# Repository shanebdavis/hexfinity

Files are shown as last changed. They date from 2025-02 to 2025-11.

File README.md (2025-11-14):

Hexfinity Logo
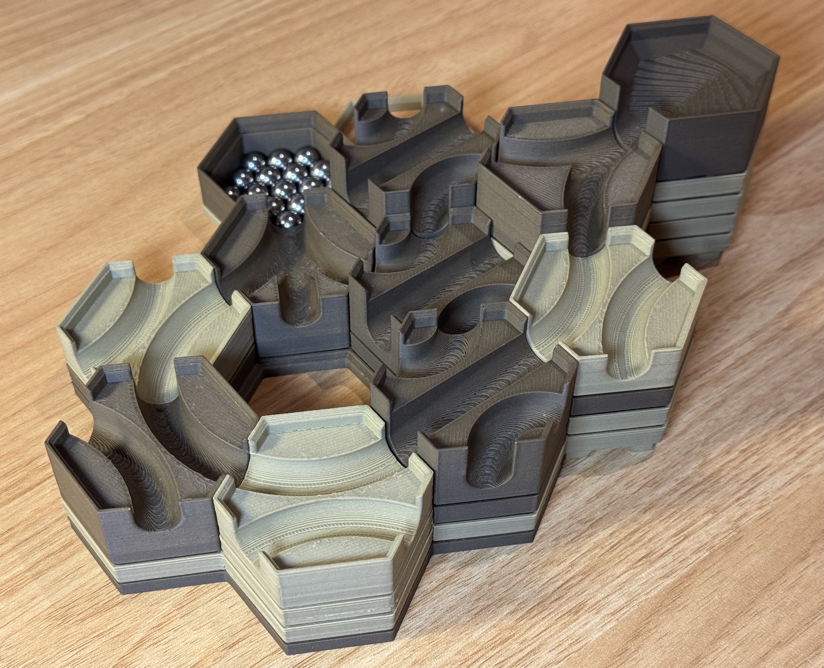
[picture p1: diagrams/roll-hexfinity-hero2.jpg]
Hexfinity Hero


> Note: I've been release new stuff all year, but I haven't had time to update this Repo. Visit me on [MakerWorld.com/en/@Kanjirevilo](https://makerworld.com/en/@Kanjirevilo) to see the latest. If you want to see me updating this repo, leave a comment there - I'm more likely to see it. If there is interest in this repo, I'll definitly do more to keep it up to date. Cheers!

# Hexfinity: Modular Hexagonal Grid System

- [Hexfinity Specification](HEXFINITY.md) Just want the specs? Go here!
- [Roll Hexfinity](ROLL_HEXFINITY.md) The ball rolling system specs
- [Stor Hexfinity](STOR_HEXFINITY.md) The hexagonal storage system specs

## Introduction

Hexagons are the bestagons! If you're here, it's because you love modular systems, you appreciate efficient tiling, and you want to build something with infinite creative possibilities. Welcome to **Hexfinity**, an open-source modular system that combines the best aspects of **ball rolling sculptures** and **hexagonal storage solutions**.

### Tribute to Gridfinity

I'm a huge fan of Zach Freedman's Gridfinity [Gridfinity on Thangs](https://thangs.com/designer/ZackFreedman/3d-model/Gridfinity%20Baseplates-60925) and [Gridfinity on YouTube](https://www.youtube.com/watch?v=ra_9zU-mnl8). I was inspired by his work to create Hexfinity. Now only is Hexfinity inspired by Gridfinity, but it is also designed to be compatible with it - at least as compatible as possible given how square grids and hexagonal grids are different.

### Why Hexagons?

- **Maximum Connectivity**: Hexagons connect to **six** neighbors, whereas squares connect to four and triangles to three. This maximizes the number of inputs and outputs, allowing for more flexible and intricate structures.
- **Efficient Space Usage**: Hexagons offer the **best ratio of area to perimeter** for tiling the plane, making them optimal for compact and efficient storage.
- **Aesthetic Appeal**: Hexagons just look better. They form natural patterns that are visually satisfying and structurally strong.
- **Better Ball Rolling**: More connections mean more pathways for balls to roll, enabling **dynamic, customizable marble runs** that are both fun and engaging.

## The Two Components of Hexfinity

Hexfinity is divided into **two major components**, each serving a unique purpose but built on the same core principles:

### 1. [RollHexfinity](ROLL_HEXFINITY.md) (The Ball Rolling System)

RollHexfinity is designed for creating highly customizable **ball rolling sculptures**. Unlike traditional marble mazes that offer limited configurations, RollHexfinity provides:

- **Modular Hexagonal Bricks**: A small set of core bricks enables infinite configurations.
- **Stackability**: Pieces can be layered while still allowing balls to roll through tunnels.
- **Standardized Ball Size**: Uses **8mm steel bearings**, a popular choice included with **Bambu Lab's Maker Kit**.
- **Controlled Slopes**: Ball paths follow structured height increments of **7mm**, ensuring smooth rolling motion.
- **Compatibility with Gridfinity**: Includes **adapter plates** that allow you to integrate RollHexfinity with the popular Gridfinity system.

### 2. [StorHexfinity](STOR_HEXFINITY.md) (The Hexagonal Storage System)

Hexfinity isn't just for rolling balls—it's also a **storage system** optimized for hexagonal layouts. StorHexfinity provides:

- **Hexagonal Containers**: Available in various sizes, maintaining modularity while maximizing storage efficiency.
- **Flexible Grid Compatibility**: Designed to integrate with square-based storage solutions.
- **Efficient Circular Storage**: Ideal for storing spherical objects (e.g., bearings, marbles, beads) more effectively than square containers.
- **Customizable Dividers**: Allows for custom compartment layouts using **60-degree and 120-degree angles**.

## Roll Hexfinity Technical Specifications

- **Roll channel diameter**: 10mm
- **Recommended ball size**: 8mm steel bearings
- **Entry and exit points**: Balls enter and exit bricks at the center of a side, with the center of the 10mm channel positioned at a multiple of 7mm from the base (e.g., 14mm, 21mm, etc.). For example, the 14mm opening starts at 9mm and extends to 19mm from the base.
- **Path grades**: Ball paths are either flat or descend by increments of 7mm, 14mm, or more. For the standard 21mm bricks, the minimum slope is **7mm over 42mm (17% grade)**.

## Building with Hexfinity

### How to Print

- BambuLab A1Mini/A1/X1/P1 Print-ready profiles are available on [MakerWorld.com/en/@Kanjirevilo](https://makerworld.com/en/@Kanjirevilo)
- Or pick the models ala carte from this repo: [models](./models)

More details on printing:

- **Material Estimate**: A full brick (~21mm tall) weighs ~9g.
- **Recommended Filament**: PLA works great. Wood PLA is a little snug at first, but it gets looser with use. PETG works fabulously.
- **Printer Compatibility**: Designed for FDM printers with a 0.4mm nozzle

### Assembly

- **Stackable Design**: Pieces interlock securely for stable constructions.
- **Tunnel-Friendly**: Tunnels are automatically created when stacking bricks with rolling paths.
- **Flexible Configurations**: Can be combined into long paths, drops, turns, and multi-level structures.

## Future Plans

- **More Adapter Plates**: Expand compatibility between Hexfinity and Gridfinity.
- **Additional Hexagonal Storage Modules**: Customizable dividers for better organization.
- **Hex-to-Grid Interchangeability**: Potential for Gridfinity pieces to sit atop Hexfinity bases.

## Contributing

This project is open-source! If you want to contribute:
1 Fork the repository.
2 Print and test the existing models.
3 Suggest improvements, new designs, or additional modular elements.
4 Submit a pull request!

## License

Hexfinity is licensed under the **Creative Commons Attribution 4.0 International (CC BY 4.0) License**. This means you are free to use, modify, remix, and share the designs **as long as you provide proper attribution** back to:

1. I prefer you link back to my [MakerWorld.com/en/@Kanjirevilo](https://makerworld.com/en/@Kanjirevilo) profile
2. But, you can also link to this github repo: [Hexfinity](https://github.com/shanebdavis/hexfinity)

And I want to hear about your creations! Add comments on one of my MakeWorld Hexfinity models or here under [issues](./issues)

# Get Started

Print, build, experiment, and enjoy! **Hexagons are the bestagons, and now you can prove it with your own hands.**

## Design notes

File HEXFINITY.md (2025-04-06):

Hexfinity Logo

# Hexfinity Specification

## The Hexfinity Grid - with Max Gridfinity Compatibility

Inspired by the Gridfinity, I started with the core gridfinity design principles:

- **42mm**: Flat-to-flat width of the hex grid(Y-repetition distance `yRep = 42mm`)
- **7mm**: Height increments

But since I'm using regular hexagons, the above dimensions imply some decidedly non-gridfinity dimensions. But what are you going to do? Hexes are just better than squares!

- **48.4974mm:** hex grid diameter (X-repetition distance `xRep = yRep / cos(π \* 30 / 180)`)
- **24.2487mm:** hex grid radius IS the tiling hex edge length (because, hexagons are the bestagons!) (`xRep / 2`)
- **12.1244mm:** 1/2 edge (`hRep / 2`)
- **36.3731mm:** 3/2 edge lengths (`3 * hRep / 2`)
- **72.7461mm:** 3 edge lengths (`3 * hRep`)

## Hexfinity Tiles (and Bricks)

While hexfinity grid defines our infinite tiling of the plane, in the real world our tiles need some clearance to fit together. To keep things easy, I also started with some nice round values:

- **48mm:** hex tile diameter
- **24mm:** hex tile radius

But that in turn implies these hex-tacular numbers:

- **41.5692:** flat-to-flat width of a hex tile

## Inter-tile Clearance

Which means the clearance between two flat tile edges is:

- **0.4308mm:** tile flat-edge-to-flat-edge clearance `42mm - 41.5692mm`
- **0.2154mm:** half the clearance `0.4308mm / 2`

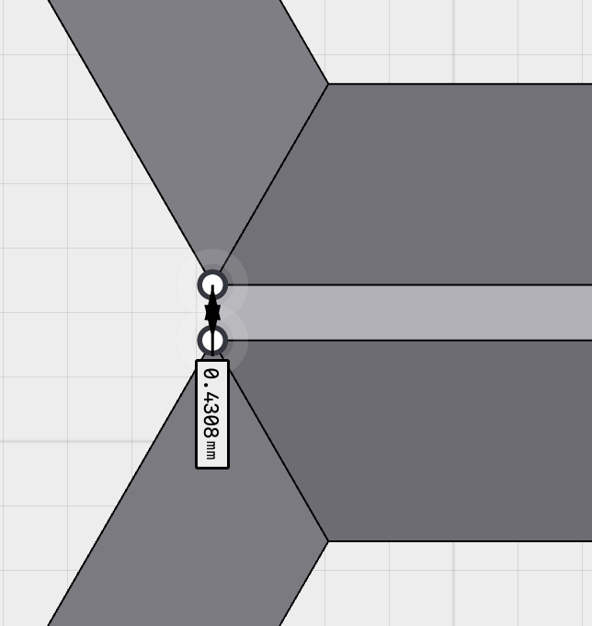
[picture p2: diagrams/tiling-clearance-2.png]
Inter-tile Clearance
- 

## Interlock

The interlock is the key to making the tiles fit together. Inspired by the Gridfinity interlock, I designed a simple interlock that fits together with a bit of clearance. The "outer" interlock rises up from the top of a tile 5mm and wraps around the "inner" interlock of the tile above. Another way to think about it is the "inner" interlock is cut out of the bottom of tile tile while the "outer" interlock is added to the top of the tile. Or, the "outer" interlock is the tongue and the "inner" interlock is the grove.

### Outer Interlock

- **Outer Interlock "tongue"** (extends on top of a tile)

  - **Profile at Hexagon _Corners_**
    - **1.8mm** thick at corners of the hexagon (**X-dimension**)
    - **5mm** outer height (**Z-dimension**)
    - **3.2mm** inner height (**Z-dimension**)
  - **1.5588mm** effective thickness of the interlock along edges of the edges of the hexagon (sin(π/3) \* 1.8)

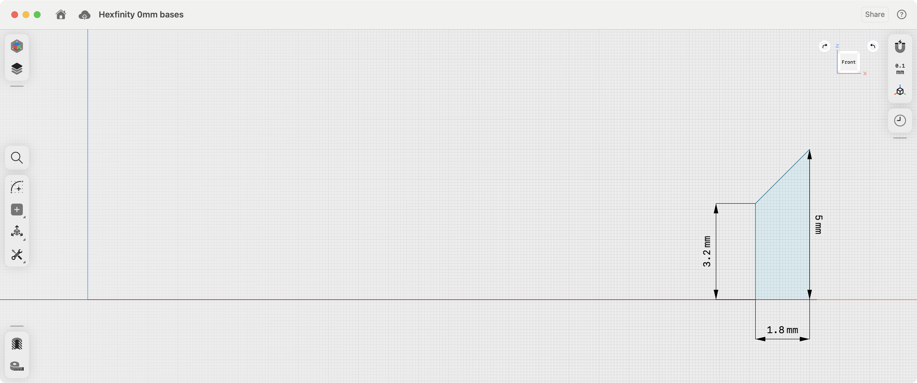
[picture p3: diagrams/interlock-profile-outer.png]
Interlock Profile Outer
- Outer interlock profile: 
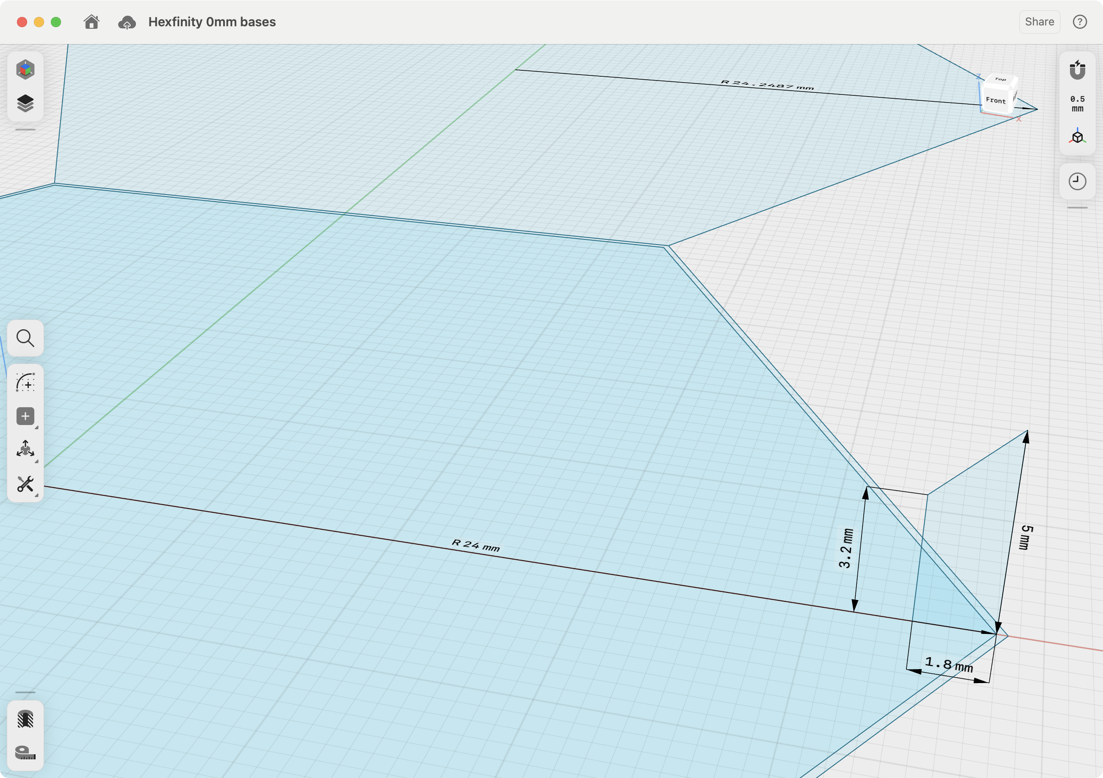
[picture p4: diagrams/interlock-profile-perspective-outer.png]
Interlock Profile Outer Perspective
- Outer interlock profile perspective: 
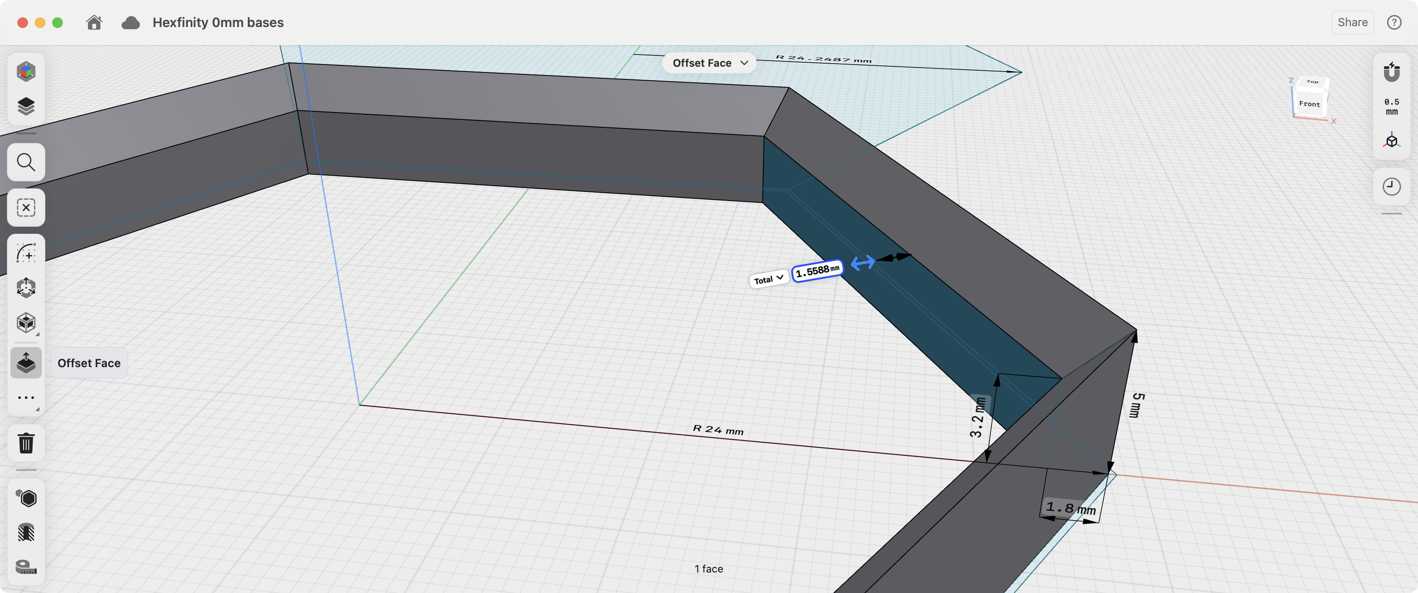
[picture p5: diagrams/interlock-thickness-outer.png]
Outer Interlock Thickness
- Outer interlock thickness: 

### Inner Interlock

- **Inner Interlock "grove"** (cut out of the bottom of a tile)

  - **Profile at Hexagon Corner**
    - **2.1mm** thick at corners of the hexagon
    - **3mm** inner height (**Z-dimension**)
    - **5.1mm** outer height (**Z-dimension**)
  - **1.8187mm** thick along edges of the hexagon (sin(π/3) \* 2.1)

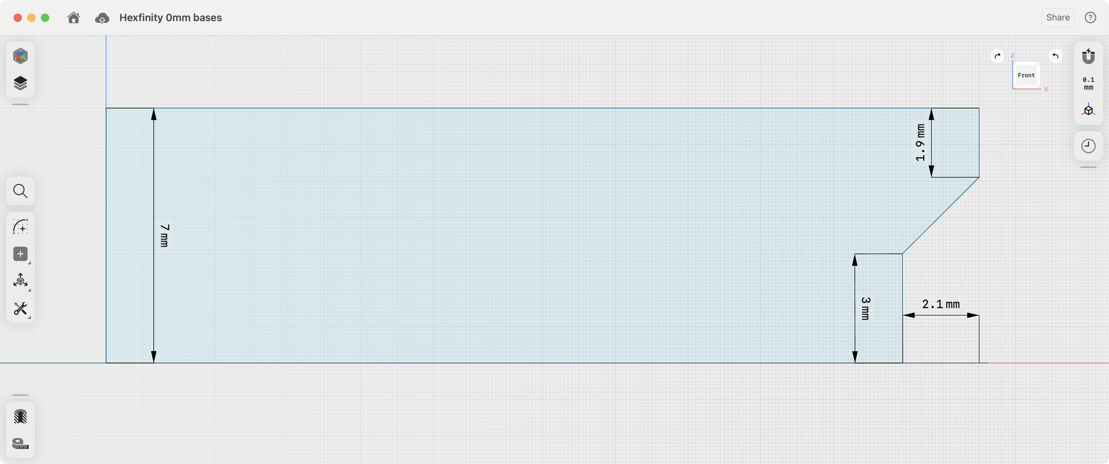
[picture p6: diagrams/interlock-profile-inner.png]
Interlock Profile Inner
- Inner interlock profile: 
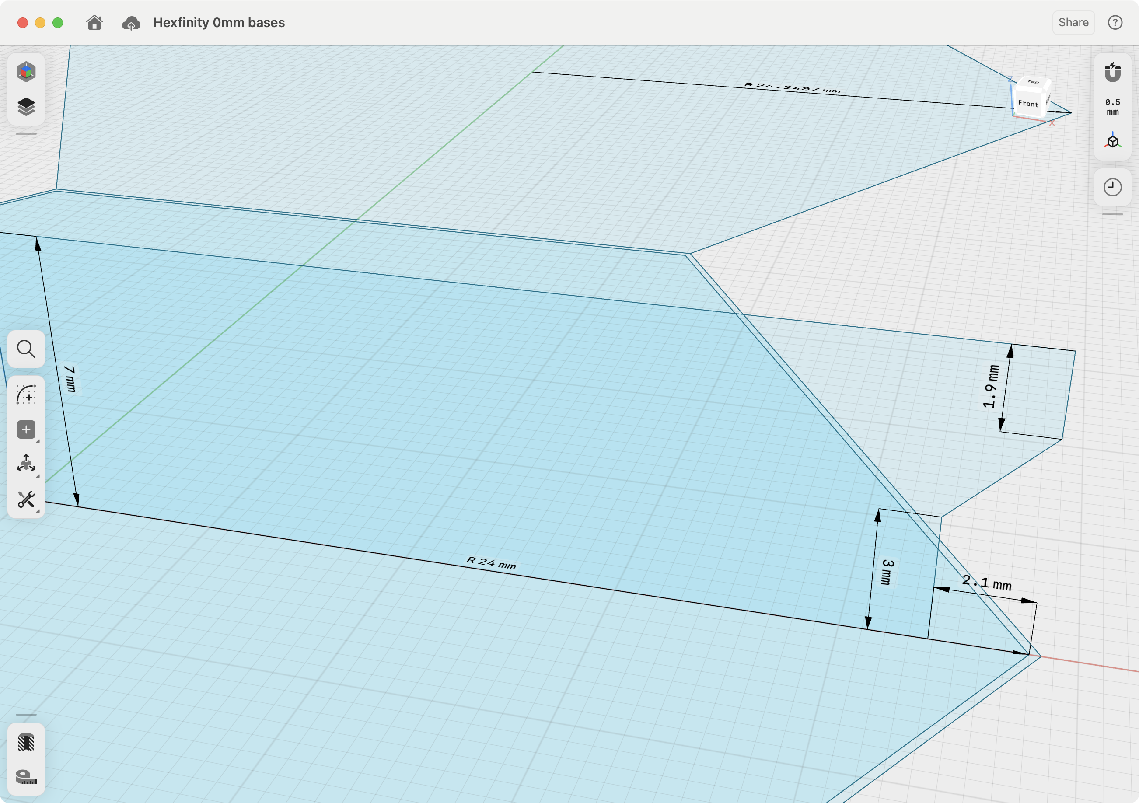
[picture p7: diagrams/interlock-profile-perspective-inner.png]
Interlock Profile Inner Perspective
- Inner interlock profile perspective: 
- Inner interlock thickness: Inner Interlock Thickness

### Both Inner and Outer Interlock

Here you can see how they fit together.

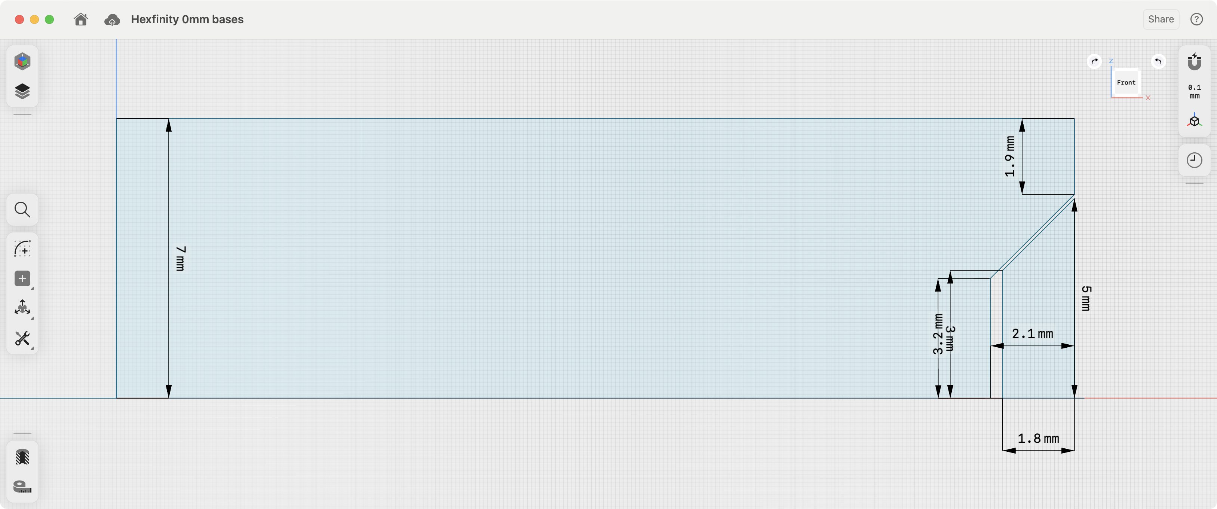
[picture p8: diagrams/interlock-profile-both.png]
Interlock Profile Both
- Interlock profile both: 
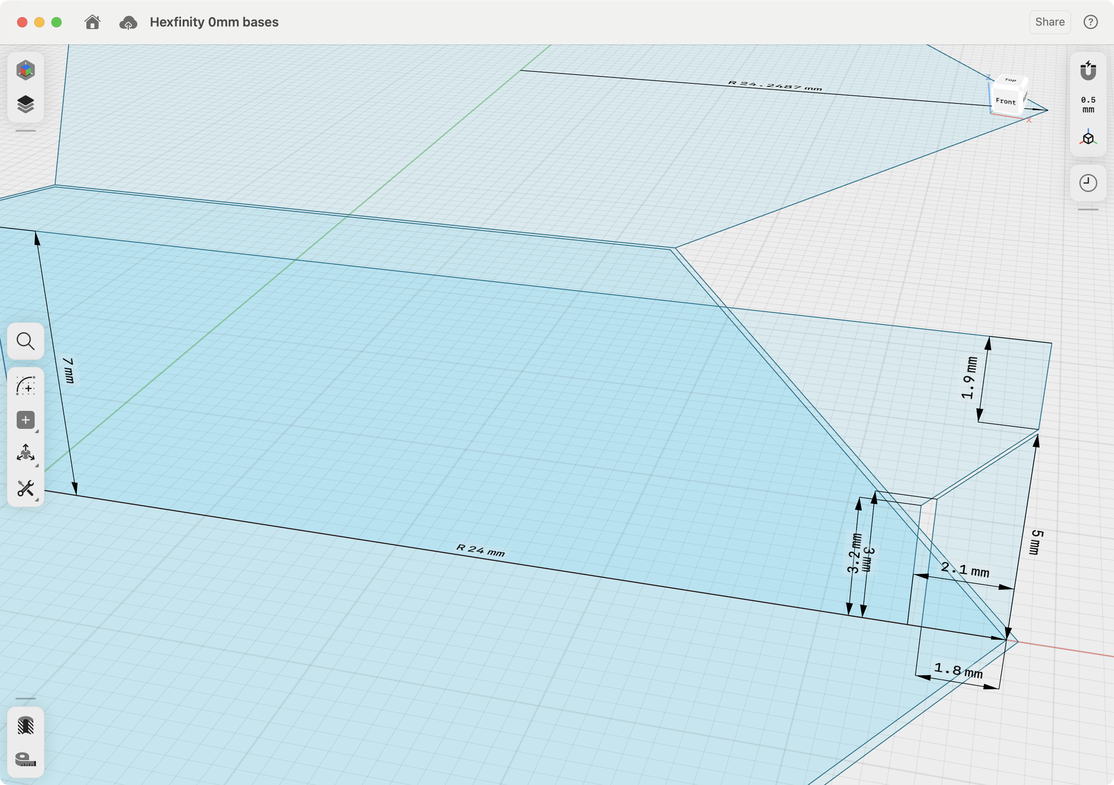
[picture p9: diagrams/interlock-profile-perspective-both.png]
Interlock Profile Both Perspective
- Interlock profile both perspective:

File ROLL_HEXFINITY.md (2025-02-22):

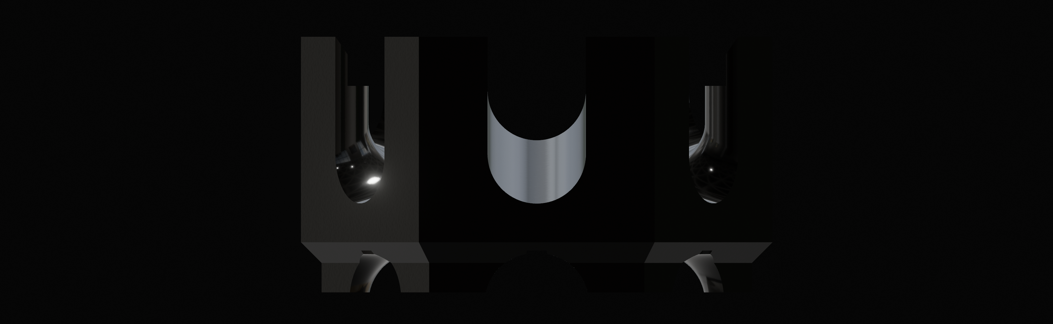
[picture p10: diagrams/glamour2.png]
Roll Hexfinity


# Roll Hexfinity - Infinite Ball Rolling System

- See the [Hexfinity Specification](./HEXFINITY.md) for the core principles of the Hexfinity ecosystem.

## Tiles, Plates and Bricks: 3x Plates == 1x Bricks (same as LEGO)

Roll Hexfinity uses the Hexfinity system, and it leverages the interlock and stainability. For easy reference, we'll use the analogy of LEGO to describe the system:

- **tile:** any placable piece in the hexfinity system
- **plate:** a 7mm hexfinity tile
- **brick:** a 21mm hexfinity tile (3x plates)

## Roll Hexfinity Tiles

Just want to print and play? Find all the models you need:

- Roll Hexfinity: [models/roll-hexfinity](./models/roll-hexfinity)
- Hexfinity Bases: [models/hexfinity-bases](./models/hexfinity-bases)
- Hexfinity Plates: [models/hexfinity-plates](./models/hexfinity-plates)

Want to customize and make your own?

- Hexfinity Reference Tiles: [models/hexfinity-reference-tiles](./models/hexfinity-reference-tiles)
- Roll Hexfinity cut-outs: [models/roll-hexfinity-cut-outs](./models/roll-hexfinity-cut-outs)

## The Roll Hexfinity Hex-to-Hex Interface System

Given the basics of Hexfinity, the key to Roll Hexfinity is how balls roll from one brick to the next:

1. **8mm:** ball diameter
2. **10mm:** ball path diameter

The center of ball paths enter and exit tiles in the center of an edge and at heights which are a multiple of 7mm from the base of the tile. The standard 3-path brick has 3 entrances at 21mm and 3 exists at 14mm:

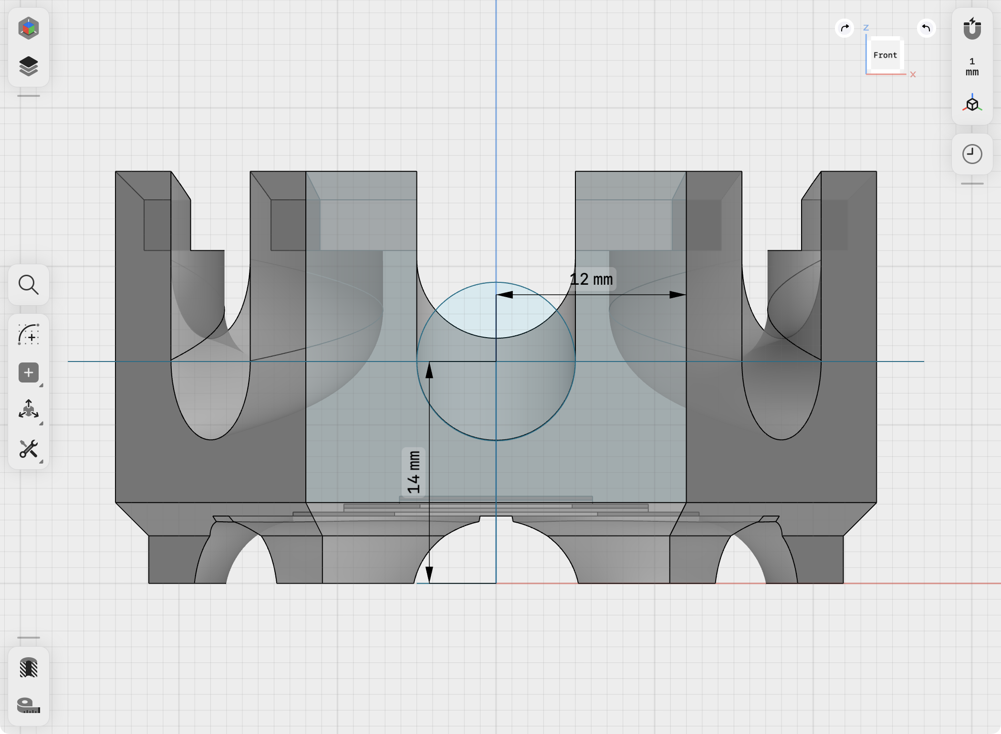
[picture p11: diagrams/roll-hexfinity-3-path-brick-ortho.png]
Ball Path Heights
- Example exit from the 3-path brick (ortho view): 
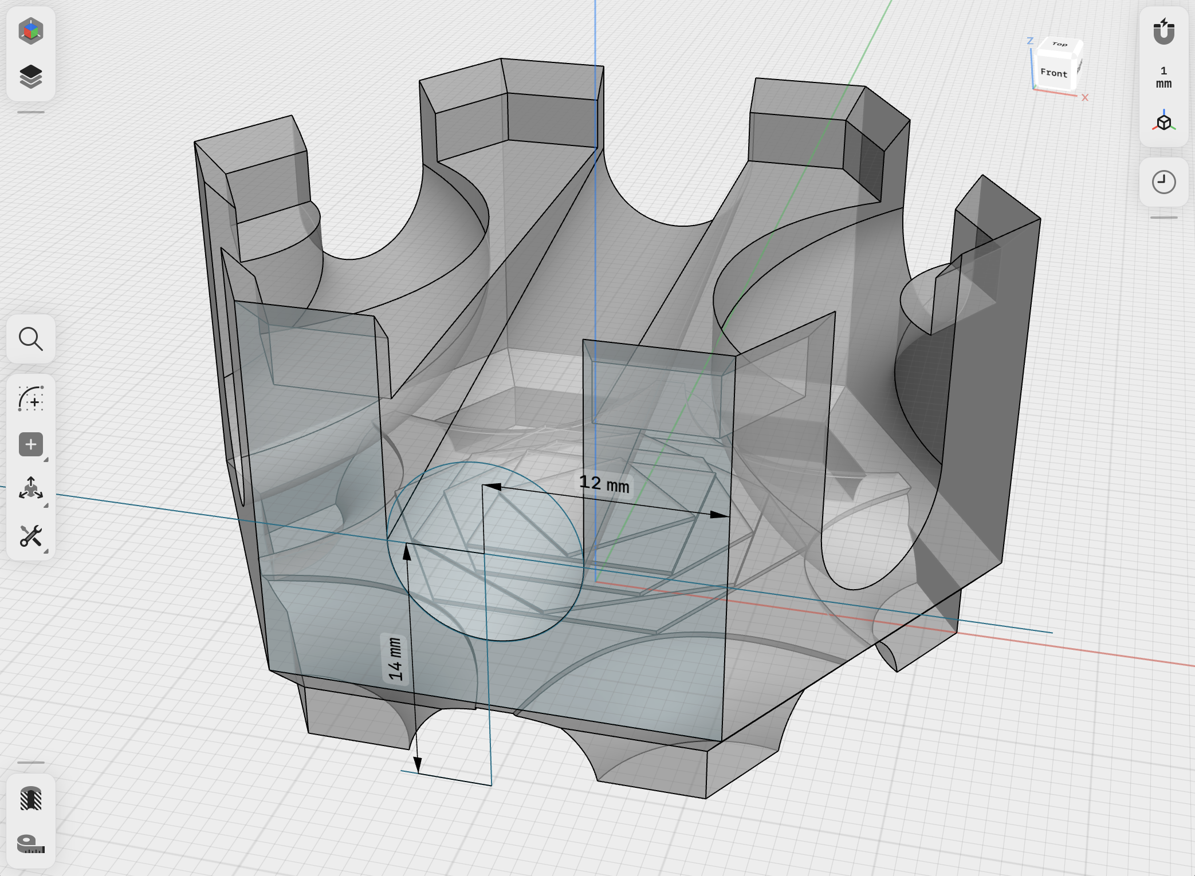
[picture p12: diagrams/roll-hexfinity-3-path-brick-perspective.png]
Ball Path Heights
- Example exit from the 3-path brick (perspective view): 

## Roll Hexfinity Clearance Trick

To make it easy for balls to roll from one brick to the next, we slightly alter the hex-to-hex interface: we lower entrances by 0.5mm. That way if two adjacent bricks are slightly misaligned, the ball will roll smoothly down to the next brick.

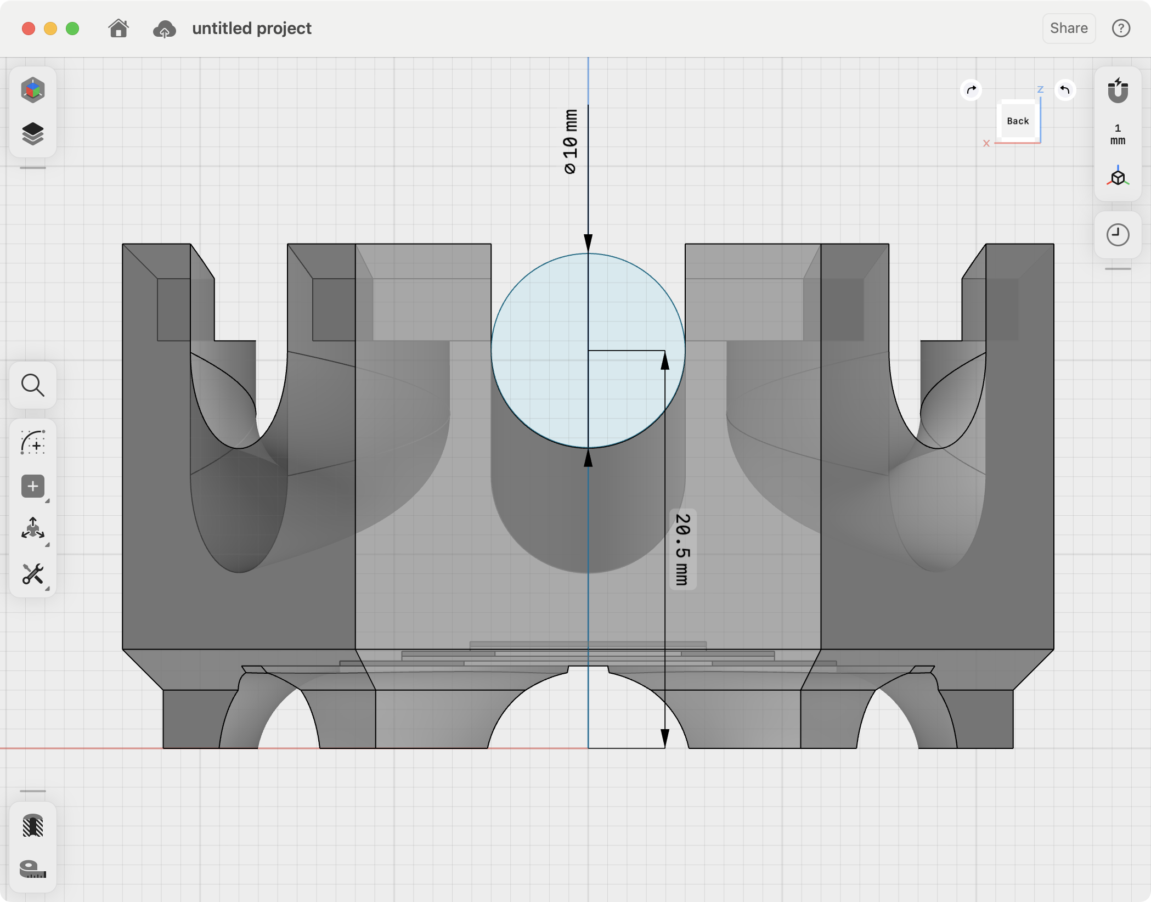
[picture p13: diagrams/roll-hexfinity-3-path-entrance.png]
Roll Hexfinity Clearance Trick
- Example entrance: 

## The Roll Hexfinity Tunnel-Compatible Base

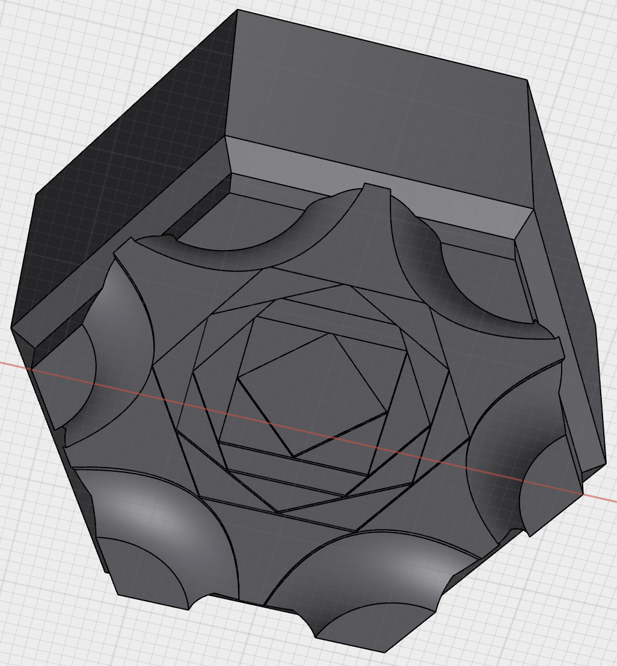
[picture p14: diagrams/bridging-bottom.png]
Bottom of a 3-path brick

What's up with the bottom of the brick?

The last, and trickiest part of the Roll Hexfinity system is the tunnel-compatible base. We need to achieve the following:

1. Roll-hexfinity tiles can be stacked without preventing balls from rolling through the tile underneath.
2. This thing needs to be 3D printable!
3. Oh, and we want it to look good :).

The first is pretty easy - we just need a clear path between every two edges of the underside of the tile. But this creates a large void in the center of the tile which 3D printers have a hard time bridging. Therefor I engineered a seemingly complex, but effective cut-out that gives the slicer the right hints to build up a bridge in layers. Last, I noticed when stacking tiles that this cut-out was visible when it didn't need to be. So, I moved the cut-out down 1mm to hide it without sacrificing the goals #1 and #2.

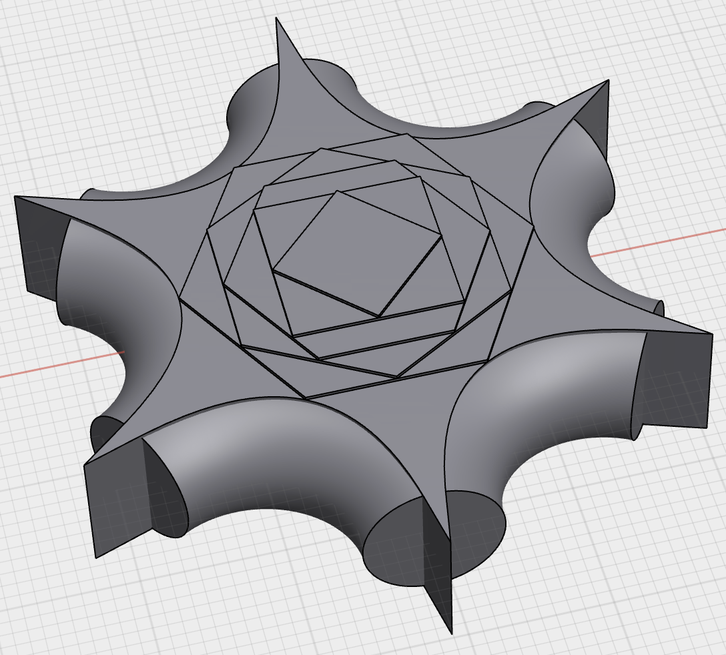
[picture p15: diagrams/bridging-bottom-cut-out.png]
Bridging Cut-Out
- Bridging cut-out:

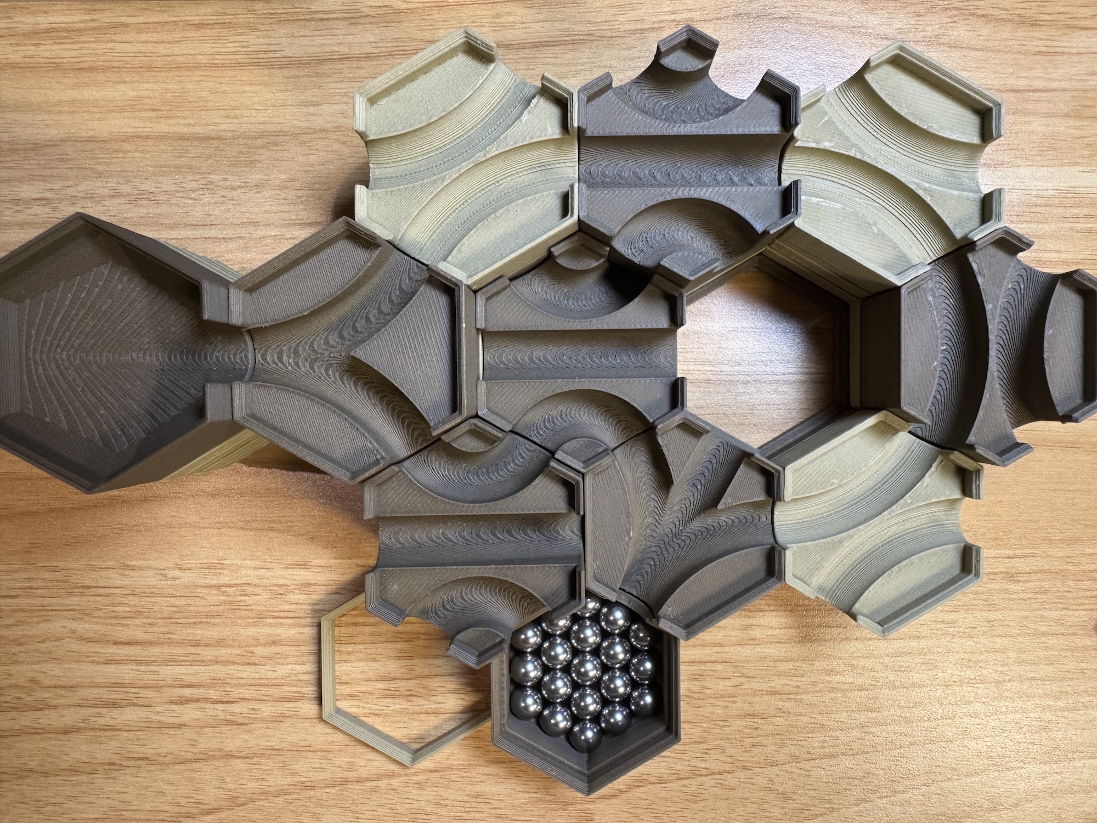
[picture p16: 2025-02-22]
diagrams/roll-hexfinity-hero.jpg

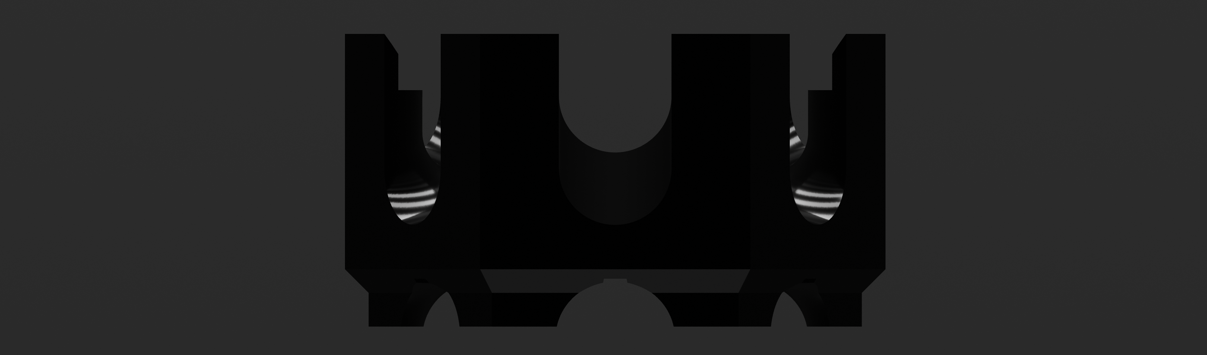
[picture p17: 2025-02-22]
diagrams/glamour.png

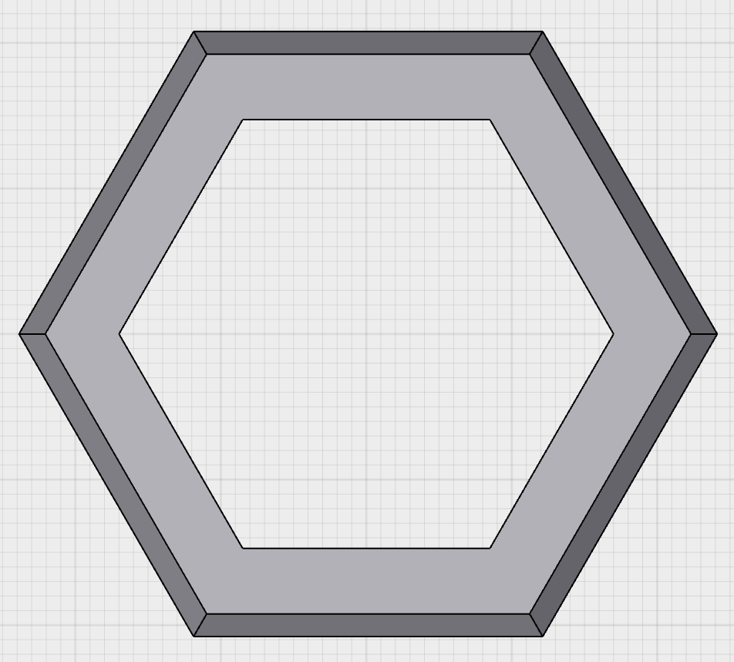
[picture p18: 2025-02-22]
diagrams/hollow-hexes.png

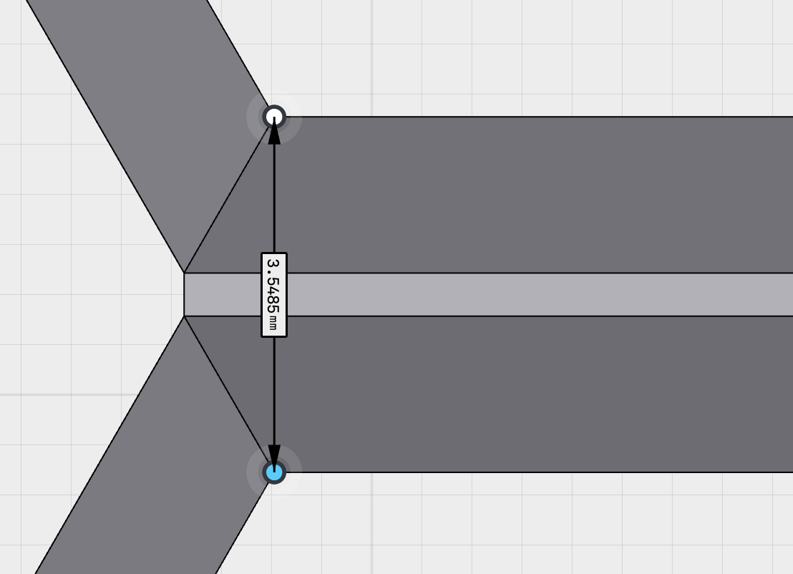
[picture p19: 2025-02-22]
diagrams/tiling-clearance-1.png

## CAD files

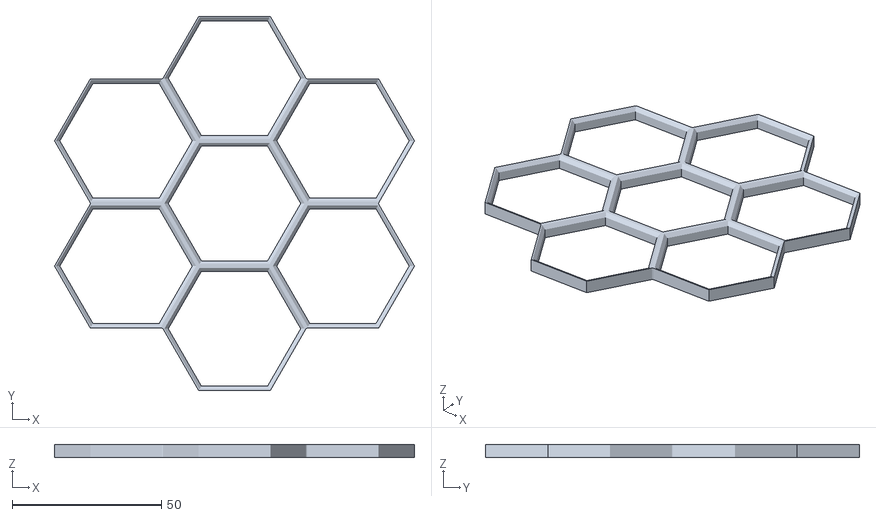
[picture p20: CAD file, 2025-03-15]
models/hexfinity-bases/Hexfinity 0mm Base 7-hex 2-3-2.stl
120.7 x 125.6 x 4.50

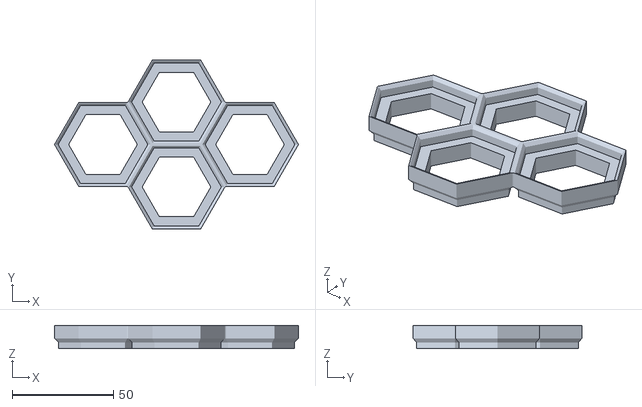
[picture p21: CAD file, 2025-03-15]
models/hexfinity-plates/Hexfinity 7mm Plate 4-hex.stl
120.7 x 83.6 x 11.5

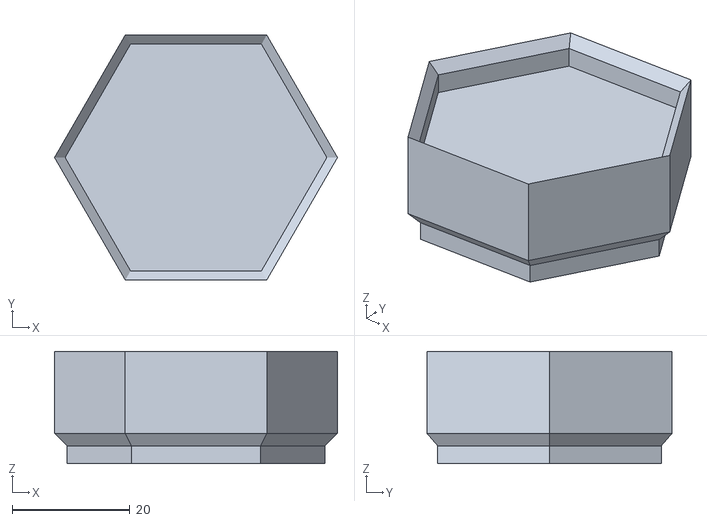
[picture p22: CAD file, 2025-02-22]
models/hexfinity-reference-tiles/Hexfinity 14mm Reference.stl
48.0 x 41.6 x 19.0

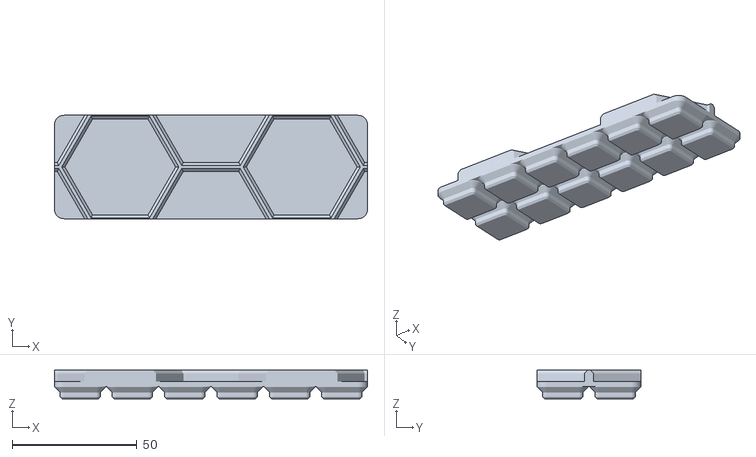
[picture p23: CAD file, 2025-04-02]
models/hexfinity-to-gridfinity/Hexfinity-QuadGridfinity Adapter Center 3x.stl
125.5 x 41.5 x 11.5

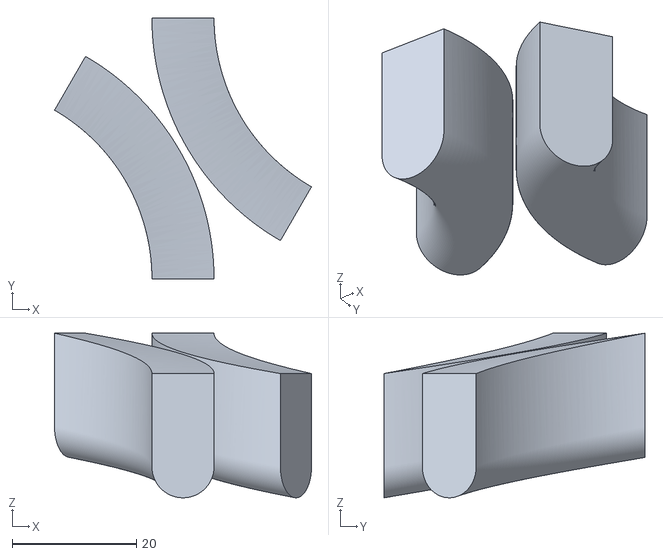
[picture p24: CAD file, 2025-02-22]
models/roll-hexfinity cut-outs/Roll Hexfinity Brick 2-path cut-out.stl
41.4 x 42.0 x 26.5

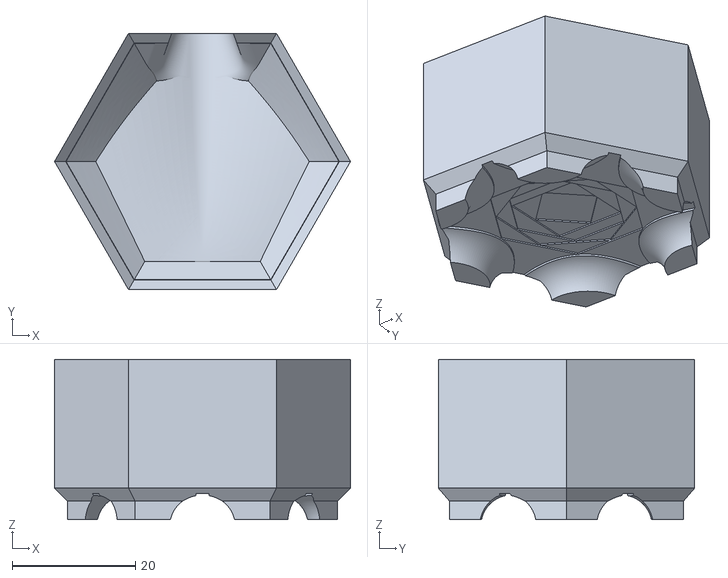
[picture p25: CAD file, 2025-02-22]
models/roll-hexfinity/Roll Hexfinity 21mm Source.stl
48.0 x 41.6 x 26.0

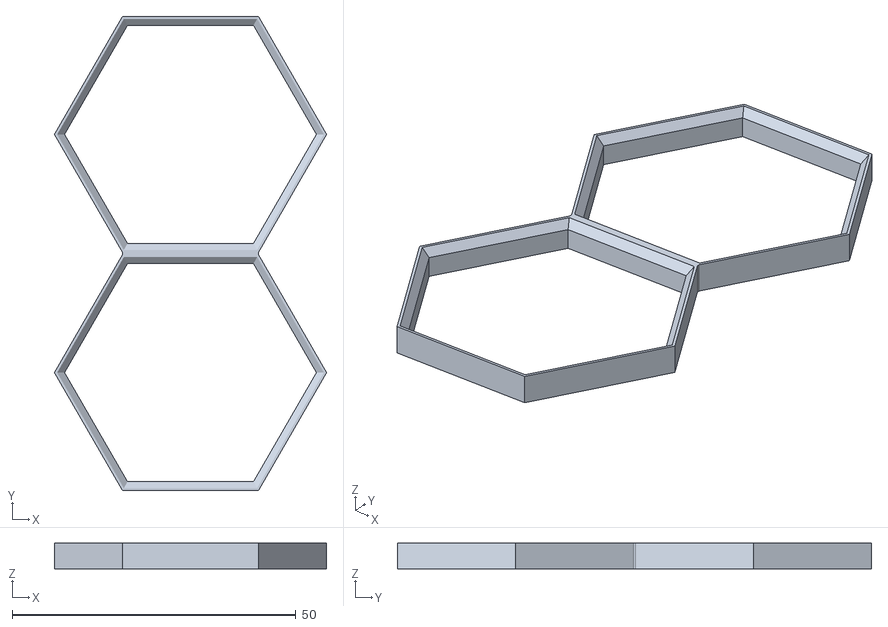
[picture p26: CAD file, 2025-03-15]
models/hexfinity-bases/Hexfinity 0mm Base 2-hex.stl
48.0 x 83.6 x 4.50

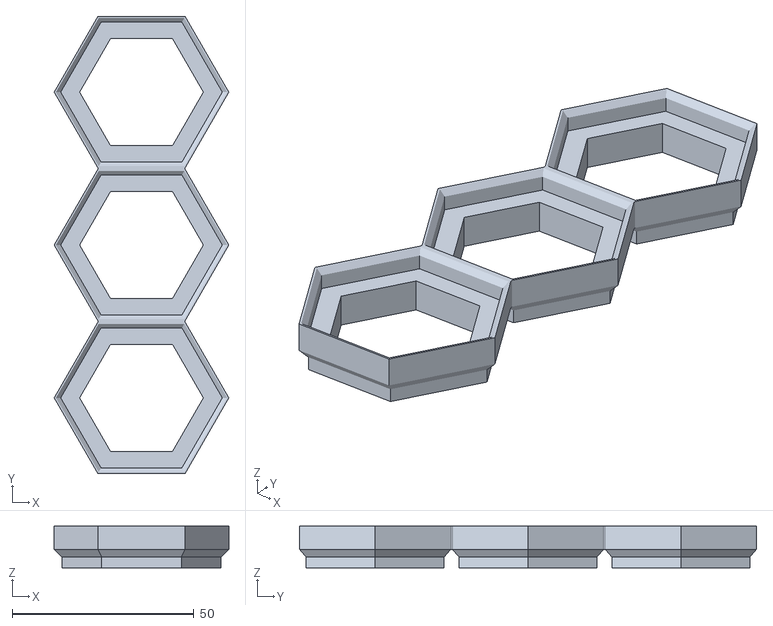
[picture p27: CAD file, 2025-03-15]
models/hexfinity-plates/Hexfinity 7mm Plate 3-hex line.stl
48.0 x 125.6 x 11.5

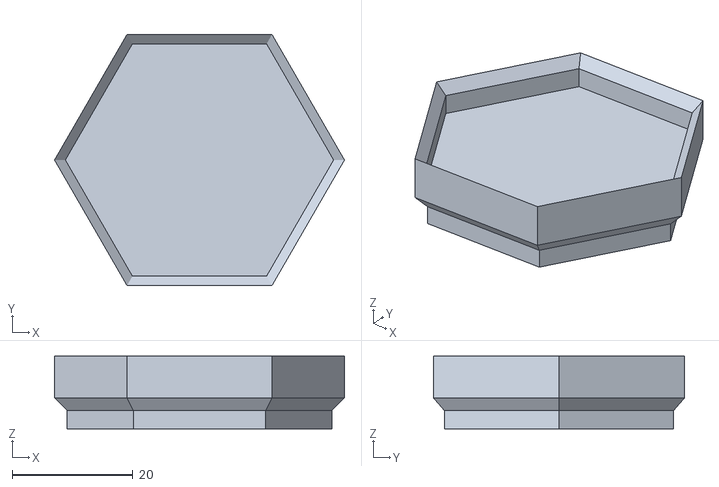
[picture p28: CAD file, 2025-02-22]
models/hexfinity-reference-tiles/Hexfinity 21mm Reference.stl
48.0 x 41.6 x 12.0

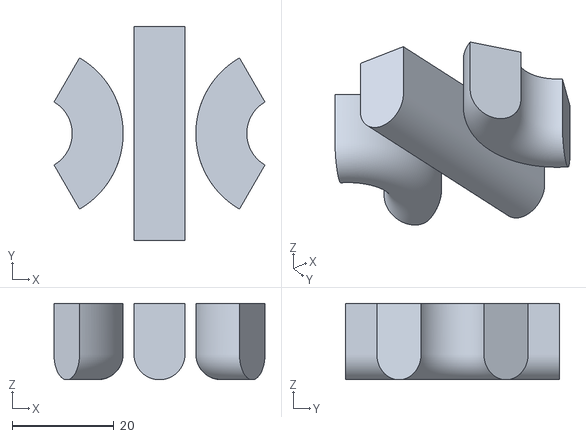
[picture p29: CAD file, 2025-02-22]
models/roll-hexfinity cut-outs/Roll Hexfinity Flat 3-path cut-out.stl
41.4 x 42.0 x 15.0

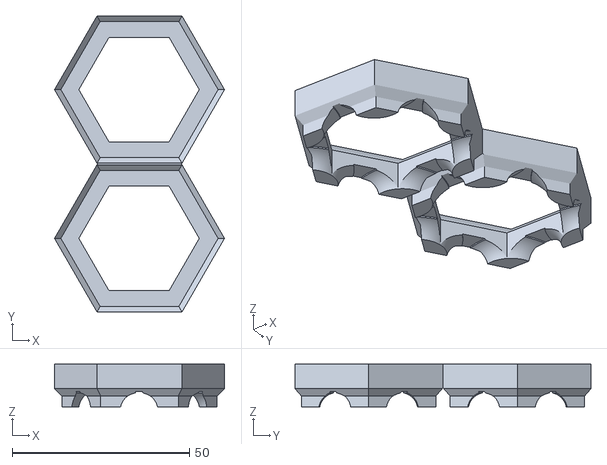
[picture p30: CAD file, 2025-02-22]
models/roll-hexfinity/Roll Hexfinity 7mm Plate 2-hex.stl
48.0 x 83.6 x 12.0

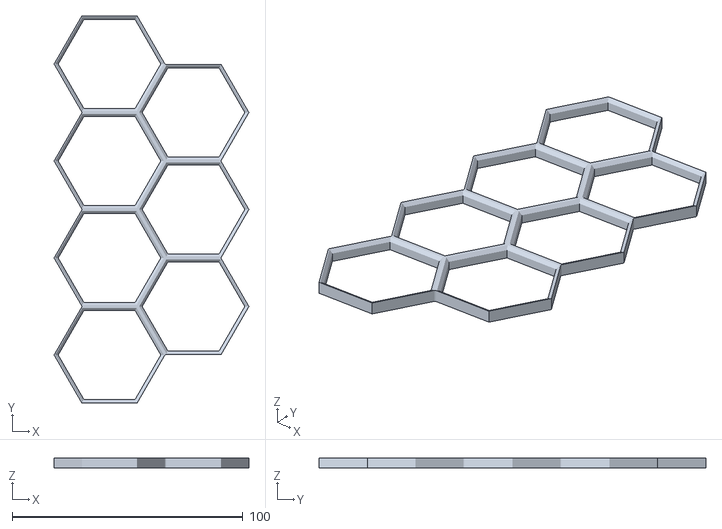
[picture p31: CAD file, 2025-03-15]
models/hexfinity-bases/Hexfinity 0mm Base 7-hex 4-3.stl
84.4 x 167.6 x 4.50

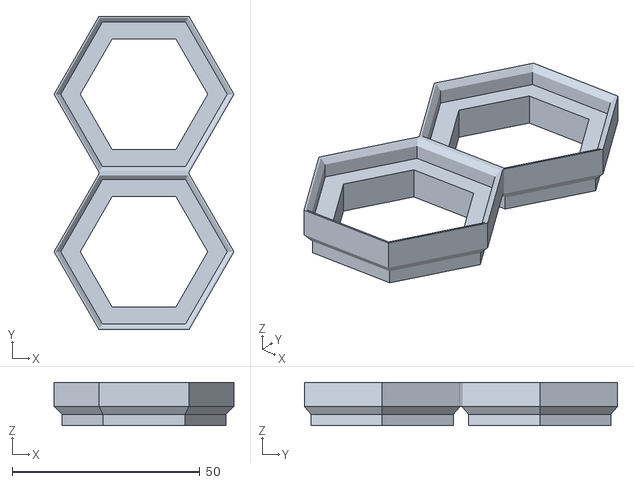
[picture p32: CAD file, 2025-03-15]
models/hexfinity-plates/Hexfinity 7mm Plate 2-hex.stl
48.0 x 83.6 x 11.5

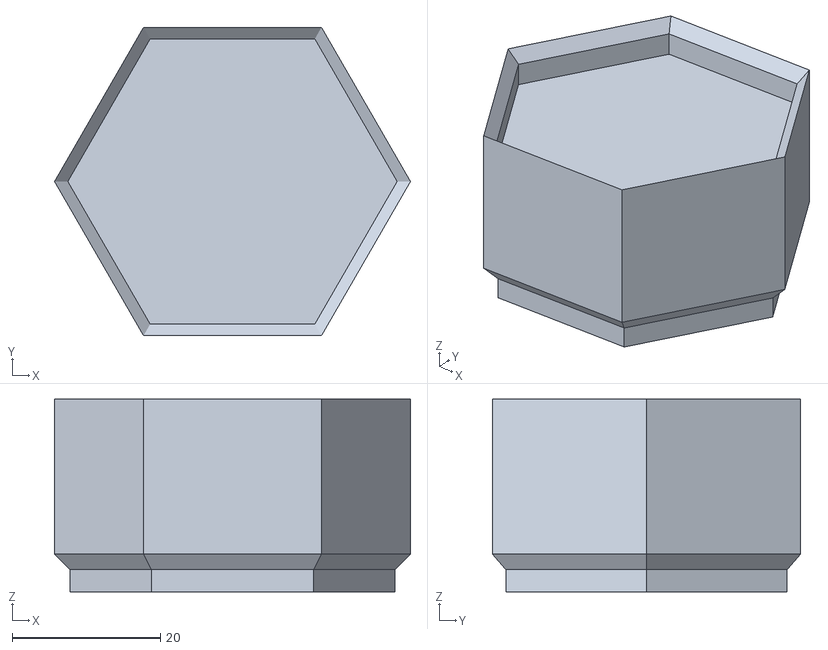
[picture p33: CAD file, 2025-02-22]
models/hexfinity-reference-tiles/Hexfinity 7mm Reference.stl
48.0 x 41.6 x 26.0

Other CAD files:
models/hexfinity-to-gridfinity/Hexfinity-QuadGridfinity Adapter Arrow Center 3x.stl
models/hexfinity-to-gridfinity/Hexfinity-Gridfinity Adapter Arrow Extension 2x.stl
models/roll-hexfinity cut-outs/Roll Hexfinity Brick 3-path cut-out.stl
models/roll-hexfinity/Roll Hexfinity 21mm Brick 3-Merge.stl
models/hexfinity-bases/Hexfinity 0mm Base 1-hex.stl
models/hexfinity-bases/Hexfinity 0mm Base 10-hex 5x2.stl
models/hexfinity-bases/Hexfinity 0mm Base 14-hex 4-3-4-3.stl
models/hexfinity-bases/Hexfinity 0mm Base 3-hex Line.stl
models/hexfinity-bases/Hexfinity 0mm Base 3-hex U.stl
models/hexfinity-bases/Hexfinity 0mm Base 3-hex radial.stl
models/hexfinity-bases/Hexfinity 0mm Base 30-hex 5x6.stl
models/hexfinity-bases/Hexfinity 0mm Base 4-hex Line.stl
models/hexfinity-bases/Hexfinity 0mm Base 4-hex.stl
models/hexfinity-bases/Hexfinity 0mm Base 5-hex line.stl
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

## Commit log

2025-02-22 wip: added all the STL files
    [Hexfinity 0mm Base 1-hex.stl, Hexfinity 0mm Base 13-hex 3-2-3-2-3.stl, Hexfinity 0mm Base 14-hex 4-3-4-3 tiling.stl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]
2025-03-15 patch/improvement: v1.1 plates and bases - slightly reduced material use and improved stacking
    [Hexfinity 0mm Base 1-hex.stl, Hexfinity 0mm Base 10-hex 5x2.stl, Hexfinity 0mm Base 13-hex 3-2-3-2-3.stl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]
2025-04-02 patch/improvement: added hexfinity-to-gridfinity adapters
    [Hexfinity-Gridfinity Adapter 3x.stl, Hexfinity-Gridfinity Adapter Arrow 3x.stl, Hexfinity-Gridfinity Adapter Arrow Extension 1x.stl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]
